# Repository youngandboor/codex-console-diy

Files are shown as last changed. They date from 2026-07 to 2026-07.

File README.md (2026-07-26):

# Codex Console DIY

Personal-use ESP32-S3 control surface compatible with Codex Micro features in
ChatGPT Desktop. The target is functional equivalence rather than a mechanical
copy: similar control grouping and lighting, Bluetooth LE, native USB, and a
single-cell rechargeable battery.

This repository is an independent compatibility experiment. It is not
affiliated with or endorsed by OpenAI or Work Louder. The compatibility
identity and undocumented protocol are used only for personal interoperability
testing.

## Current milestone

Phase 0 provides:

- the exact 63-byte vendor HID framing used by the Core2 reference project;
- a bounded, allocation-free receive assembler;
- BLE and native USB HID transports on ESP32-S3;
- USB-first transport routing, with BLE fallback;
- the observed Codex RPC methods and six Agent status values;
- two breadboard inputs on GPIO4/GPIO5 using external Agent 1/Agent 2 buttons;
- native unit tests for framing, fragmentation, validation, and recovery.

Physical key scanning, RGB output, the joystick, encoder, fuel gauge, and sleep
policy are intentionally the next milestone. The USB protocol is implemented
as an informed compatibility hypothesis and still requires validation against
ChatGPT Desktop before a PCB is ordered.

## Build

```sh
pio test -e native
pio run -e esp32-s3-devkitc-1
```

For the development-board smoke test, use an ESP32-S3 DevKitC-1 native USB
port. Connect normally-open buttons from GPIO4 and GPIO5 to a shared GND;
pressing them sends Agent 1 and Agent 2 events respectively. The firmware
enables the GPIO internal pull-ups, so no external resistors are required. The
earlier GPIO0/BOOT bench input was only used for first-board validation and is
no longer used as a user control.

## Project boundaries

- `src/protocol`: transport-independent HID framing and Codex RPC behavior.
- `src/transports`: BLE HOGP and ESP32-S3 native USB HID.
- `src/main.cpp`: Phase 0 orchestration only.
- `docs/hardware-v1.md`: interaction layout, electrical architecture, and PCB
  gates.
- `docs/development-plan.zh-CN.md`: parallel firmware, product, and PCB plan.
- `docs/purchase-checklist.zh-CN.md`: staged beginner purchase checklist and
  order gates.
- `docs/wireless-audio-options.zh-CN.md`: 2.4 GHz dongle and BLE Audio tradeoff
  analysis.
- `docs/hardware-validation-log.zh-CN.md`: dated physical-hardware validation
  results.
- `docs/validation.md`: tests required before moving from breadboard to PCB.
- `hardware/rev-a`: integrated Alpha PCB, enclosure, placement, BOM, and 1:1
  mechanical design baseline.

The original Core2 project remains a read-only behavioral reference in the
sibling `codex-micro-4-core2` directory.

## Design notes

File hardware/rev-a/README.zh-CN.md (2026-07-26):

# Codex Console Alpha Rev A

本目录是第一版集成样品的设计基线。目标不是一次量产成功，而是用一套可装配的
PCB、外壳和真实控件同时验证功能、手感、灯光、电源和装配。

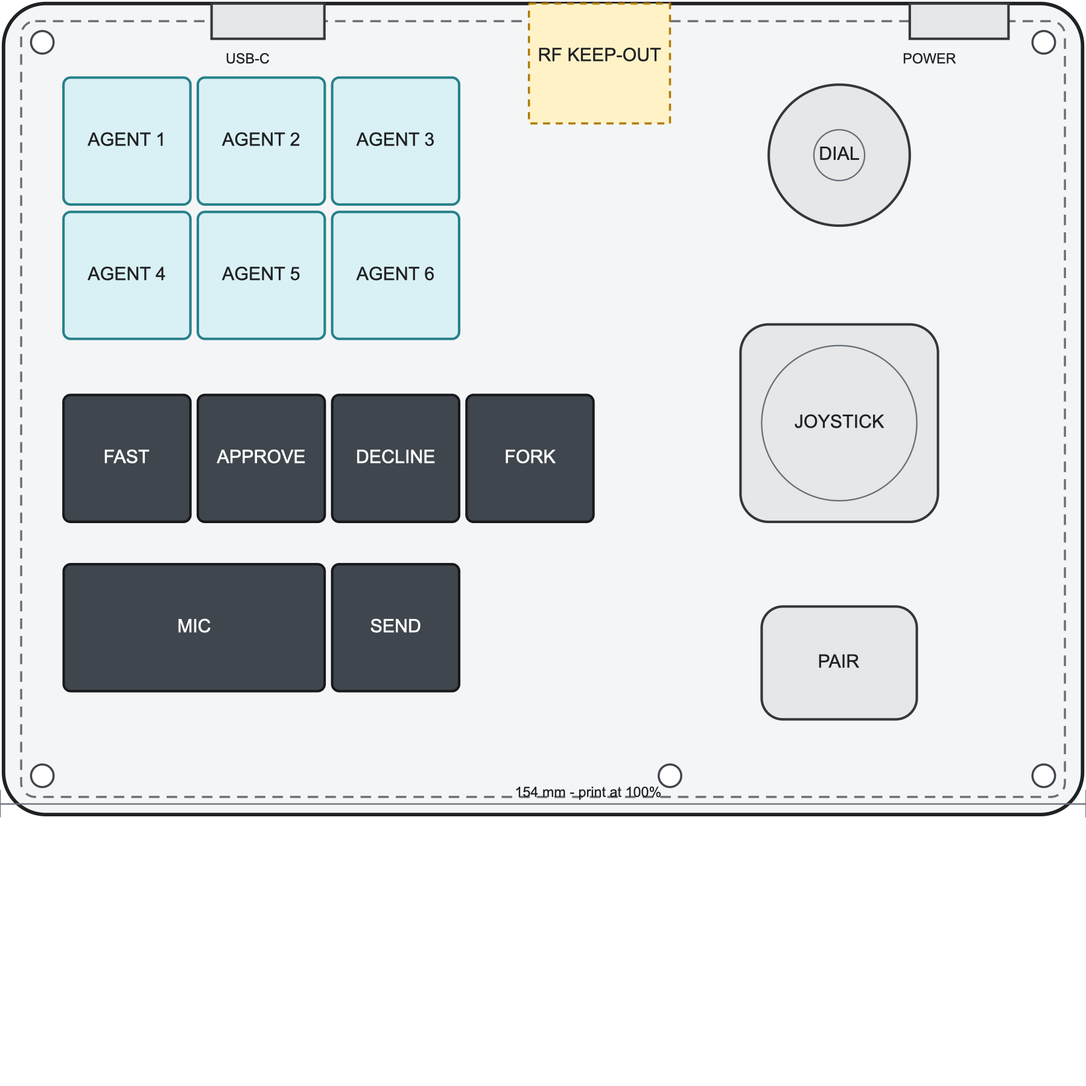
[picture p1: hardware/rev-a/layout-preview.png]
Rev A 顶视布局


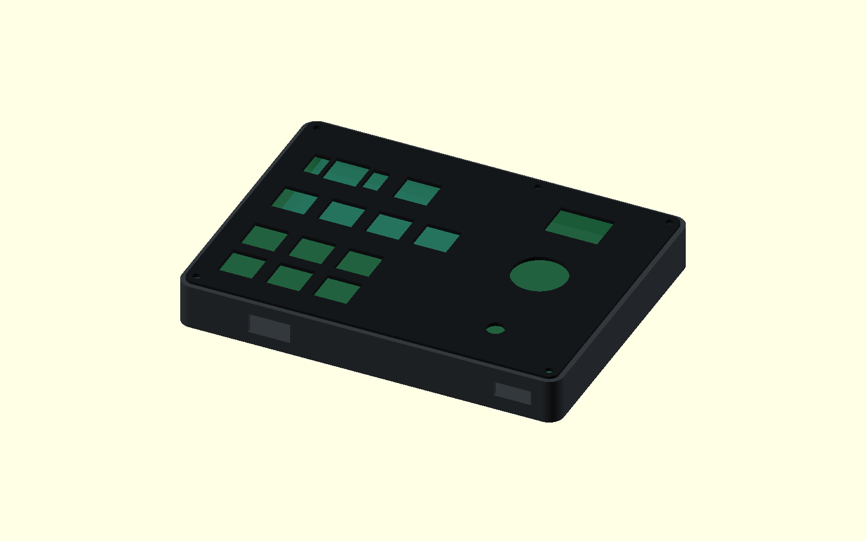
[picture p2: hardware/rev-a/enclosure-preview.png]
Rev A 外壳参数模型


## 已冻结的产品方向

| 项目 | Rev A 决策 |
| --- | --- |
| 外壳外形 | 154 x 116 mm，圆角桌面控制台 |
| 主 PCB | 148 x 110 mm，4 层，1.6 mm，优先 SMT 贴片 |
| 按键 | 12 个 MX 热插拔轴，PCB 同时兼容 3 脚和 5 脚，19.05 mm 间距 |
| 键帽 | XDA 等高；6 个磨砂半透明 1U Agent，5 个深灰 1U Command，1 个深灰 2U Mic |
| 轴体 | Alpha 默认 Gateron G Pro 3.0 Brown，透明上盖、5 脚；热插拔允许后续替换 |
| Mic 稳定器 | PCB 安装 2U 螺丝卫星轴 |
| 旋钮 | Alps Alpine EC11E15244G1，30 段、15 脉冲、带按压、20 mm D 轴 |
| 摇杆 | Alps Alpine RKJXV122400R，回中双轴、10 kOhm、带中心按压 |
| 主控 | ESP32-S3-WROOM-1-N8R8 |
| 连接 | BLE HID + 原生 USB 2.0 Full Speed，USB 有线优先 |
| 灯光 | 12 个按键灯 + 8 个边缘灯，共 20 个 SK6812MINI-E |
| 电池 | 预留受保护 1S 604070 LiPo，最大包络 70 x 40 x 7 mm，JST-PH 2.0 |
| 充电 | BQ24074 PowerPath，允许插线使用和充电 |
| 板载麦克风 | 预留 PDM 器件和声孔，Rev A 默认 DNP，不启用 USB Audio |

Mic 键在 Rev A 中继续调用电脑麦克风。这保持与已经验证的 Codex Micro HID 行为
一致。板载麦克风只有在 USB Audio 复合设备和无线语音方案分别验证后才装配。
Rev A 不集成专用 2.4 GHz 接收器，也不承诺 BLE Audio；两者继续作为后续独立版本，
不阻塞当前 BLE HID + USB 样品。

## 电气构成

```mermaid
flowchart LR
    USB["USB-C VBUS"] --> ESD["USB/ESD 保护"]
    ESD --> CHG["BQ24074 PowerPath"]
    BAT["1S 受保护 LiPo"] --> CHG
    BAT --> GAUGE["MAX17048 电量计"]
    CHG --> SYS["系统电源轨"]
    SYS --> REG3["TPS63070 3.3 V"]
    SYS --> REG5["TPS61023 5 V RGB"]
    REG3 --> MCU["ESP32-S3-WROOM-1-N8R8"]
    REG5 --> LED["20 x SK6812MINI-E"]
    MCU --> MATRIX["4 x 4 按键矩阵"]
    MCU --> ENC["EC11 旋钮"]
    MCU --> JOY["双轴摇杆"]
    MCU --> USBHID["原生 USB HID"]
    MCU --> BLE["BLE HID"]
```

## 坐标和堆叠

- 所有平面坐标以外壳左上角为 `(0, 0)`，单位为 mm。
- PCB 位于外壳内侧，每边留 3 mm。
- PCB 下方预留 9 mm 电池层，并使用绝缘电池托盘隔开热插拔轴座和电芯。
- MX 定位板到 PCB 的名义距离为 5.0 mm，定位板厚 1.5 mm。
- 外壳主体高度 18 mm；键帽和旋钮露出主体，不计入 18 mm。
- 后边缘布置 USB-C、电源开关和模块天线区域；天线前方及上下层不得放置金属。

## 文件

- `layout.svg`：154 x 116 mm 的 1:1 顶视布局，可按 100% 比例打印。
- `enclosure.scad`：参数化底壳、定位板、孔位和占位体。
- `placement.csv`：控件中心和机械包络，PCB 与外壳共用。
- `mechanical-placement.kicad_pcb`：四层 PCB 板框、安装孔、控件包络和天线/电池区的
  KiCad 机械基线；它不是已布线生产板。
- `mechanical-placement-preview.png`：KiCad 机械基线的独立导出预览。
- `lceda/Codex Console Rev A.eprj2`：嘉立创 EDA 专业版 V3.2.166 的正式本地工程；
  原理图和 PCB 将以此为后续主设计文件。
- `net-map.csv`：GPIO、矩阵和主要网络分配。
- `pcb-rules.md`：四层板、电源、USB、天线和可制造性约束。
- `bom.csv`：Rev A 关键电气与机械 BOM；小阻容在原理图完成时补齐数值。
- `sources.md`：关键芯片与控件的原厂资料入口。
- `procurement.zh-CN.md`：机械样品、PCBA 物料和电池的分批下单边界。
- `release-checklist.zh-CN.md`：PCB 下单和外壳打印前必须关闭的 P0 检查项。

## 当前完成度

机械基线已使用 KiCad 10.0.5 执行 DRC，结果为 0 条违规、0 个未连接项；参数外壳已
使用 OpenSCAD 2021.01 完成编译渲染。这里的 DRC 只证明板框、安装孔和机械图层合法，
不代表尚未绘制的电路已经通过验证。

同一机械基线已导入嘉立创 EDA 专业版工程，文档名为 `mechanical-placement`。空白的
`PCB1` 和 `Schematic1` 是软件创建工程时生成的占位文档，不代表导入失败。

这是可用于原理图捕获和结构样件的 Rev A 基线，还不是可以直接发板的生产包。发板前
必须完成：正式 KiCad 原理图、封装核对、ERC、PCB 布线、DRC、Gerber/钻孔复查、
3D 干涉检查和电池极性复核。第一次只投 5 片 PCB 和 2 套打印外壳。

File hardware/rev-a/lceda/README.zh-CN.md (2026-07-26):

# 嘉立创 EDA 专业版工程

- 软件版本：嘉立创 EDA 专业版 `V3.2.166`
- 工程文件：`Codex Console Rev A.eprj2`
- 保存模式：本地半离线工程
- 当前内容：`Board1 / Schematic1 / P1 / PCB1 / mechanical-placement`

`mechanical-placement` 已从 `mechanical-placement-kicad.zip` 导入，并在 PCB 编辑器中
确认可见：包含 148 x 110 mm 板框、5 个 M3 安装孔、12 键包络、旋钮、摇杆、触控区、
电池区和天线区。原始的 `PCB1` 仍是空白占位页。

`Schematic1 / P1` 仍为空白，因为此前完成的是产品布局和 PCB 机械基线，并不是正式
电路原理图。后续将在这里完成 ESP32-S3、USB、电源、矩阵、旋钮、摇杆、RGB 的电路、
封装、布线、ERC、DRC 和生产文件导出。

不要直接用 SQLite 工具修改 `.eprj2`。所有设计变更必须通过嘉立创 EDA 专业版完成，
关闭或保存工程后再提交 Git。

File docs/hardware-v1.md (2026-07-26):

# Hardware v1 specification

## Interaction layout

The control surface keeps the original functional grouping without copying its
case or industrial design:

- six translucent Agent keys in a 3 x 2 block, each with independent RGB;
- six Command keys grouped below the Agent keys;
- a 2U Mic key and five 1U Command keys are preferred for a familiar layout;
- a push rotary encoder in the upper-right control area;
- a two-axis analog joystick beside or below the encoder;
- one separate capacitive or tactile communication control near the lower-left;
- perimeter RGB for recording, processing, connection, and charging effects.

Suggested logical arrangement:

```text
AGENT 1   AGENT 2   AGENT 3                 DIAL
AGENT 4   AGENT 5   AGENT 6               JOYSTICK
FAST      APPROVE   DECLINE    FORK
MIC (2U)             SEND      COMM/PAIR
```

The functional input count is 12 keys plus encoder push. The matrix should be
4 x 4 with one diode per switch, leaving spare positions for a local layer or
diagnostic key. The encoder quadrature lines and joystick axes remain direct
MCU inputs.

## Lighting

Use one addressable chain with explicit logical ranges:

| Range | Count | Purpose |
| --- | ---: | --- |
| Agent RGB | 6 | Host-provided task color and breathing state |
| Command RGB | 6 | Command feedback and local press feedback |
| Perimeter RGB | 8 | Moving voice, processing, pairing, and charge effects |

The firmware must cap global brightness and estimated LED current. Agent state
colors take priority over decorative effects. USB and battery operation use the
same visual policy; plugging in USB must not force all LEDs to full brightness.

## Core electronics

- MCU/module: ESP32-S3-WROOM-1, 8 MB flash is sufficient; PSRAM is optional.
- USB: native ESP32-S3 USB D-/D+ on GPIO19/GPIO20, USB-C device connector,
  5.1 kohm CC pull-downs, ESD protection, and 22/33 ohm series footprints.
- Power: 1-cell protected LiPo, nominal 1,500-2,000 mAh.
- Charger: BQ24074-class charger with power-path/load sharing. Do not connect a
  basic charger module, battery, USB rail, and system load in parallel.
- 3.3 V: regulator rated for at least 500 mA with the decoupling recommended by
  Espressif.
- Fuel gauge: MAX17048 or equivalent 1-cell gauge over I2C.
- RGB logic: dual-supply level shifter between 3.3 V MCU data and the LED rail.
- Controls: MX-compatible hot-swap footprints for ease of DIY assembly, EC11
  push encoder, and a spring-centered two-axis analog joystick.
- Service: physical power switch, reset, boot pads/button, UART pads, battery
  connector, and current-measurement jumper.

## Proposed GPIO allocation

This allocation avoids USB pins, boot strapping pins, and pins that may be
occupied by octal flash/PSRAM variants:

| Function | GPIO |
| --- | --- |
| Matrix rows | 4, 5, 6, 7 |
| Matrix columns | 8, 9, 10, 11 |
| Encoder A/B | 12, 13 |
| Joystick X/Y (ADC) | 1, 2 |
| Communication touch control | 14 |
| Addressable RGB data | 15 |
| Fuel gauge I2C SDA/SCL | 17, 18 |
| USB D-/D+ | 19, 20 |
| Charger status | 16, 21 |
| UART service pads | 43, 44 |

Encoder push occupies one position in the 4 x 4 matrix. Reserve the other
unused matrix positions rather than assigning them to mandatory v1 features.
Place a 510 ohm series footprint at the MCU end of the touch trace.

## Transport policy

Both transports may remain initialized, but only one sends user actions:

1. A mounted and ready USB HID connection has priority.
2. If USB is only supplying power or charging but is not enumerated, BLE stays
   active.
3. After USB unmounts, release all active logical controls before switching to
   BLE so no key remains logically held.
4. RPC responses return over the transport that received the request.
5. Lighting commands from the active transport win; inactive-host lighting is
   ignored after the protocol validation milestone.

## PCB gates

Do not order the integrated battery PCB until all of these pass on a DevKitC-1:

- ChatGPT Desktop recognizes both BLE and USB identities;
- Agent and Command actions work over both transports;
- USB priority does not duplicate a press on BLE;
- disconnect during a held key produces a clean release after reconnection;
- six Agent status colors are received and replayed reliably;
- native USB is revalidated after every descriptor or SDK change.

For Alpha Rev A, the user has explicitly accepted an integrated-board fast track after USB, BLE,
two-button input, and USB/BLE priority were validated. Matrix, RGB, encoder, joystick, and battery
validation may therefore happen on the first five integrated boards. This exception does not waive
ERC, DRC, footprint, USB-impedance, antenna-keepout, battery-polarity, or staged-power-up reviews.

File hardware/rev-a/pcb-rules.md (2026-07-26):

# PCB Rev A rules

## Stackup and fabrication

- Four layers, 1.6 mm finished thickness, 1 oz outer copper.
- L1: components and short critical signals.
- L2: uninterrupted ground plane except the certified module antenna keepout.
- L3: power distribution and slow signals.
- L4: hot-swap sockets, reverse RGB, diodes and non-critical routing.
- Default minimum track/space 0.15/0.15 mm; use 0.20 mm where density permits.
- Signal vias 0.45/0.20 mm finished; do not use via-in-pad for the Alpha.
- All QFN exposed pads require paste-window reduction and ground thermal vias based on the
  manufacturer's current land pattern.

## USB

- Route GPIO19/GPIO20 as a 90 Ohm differential pair using the PCB supplier's actual stackup.
- Keep pair length mismatch below 0.5 mm and avoid vias. Do not guess the final width/gap before
  selecting the fabricator impedance table.
- Place the 22 Ohm series footprints at the ESP32 module, and the ESD array at the connector.
- Provide 5.1 kOhm Rd resistors on both USB-C CC pins. Do not connect USB-C SuperSpeed pins.
- Set the BQ24074 input-current limit conservatively for a USB host and verify suspend/configured
  behavior during schematic review; do not assume every USB-C source permits 1.5 A or 3 A.
- Keep switching inductors and the RGB data edge away from the USB pair.

## RF

- Put the ESP32-S3-WROOM-1 antenna at the rear board edge.
- Copy the current Espressif module land pattern and antenna keepout from the official datasheet.
- No copper, traces, battery, screws, metal plate or shield above or below the antenna keepout.
- Use a plastic rear wall near the antenna; the switch plate must stop before the keepout.

## Power

- VBUS feeds BQ24074 IN through protection; BQ24074 OUT feeds the 3.3 V and 5 V converters.
- The physical power switch controls converter EN pins. Charging and fuel measurement remain
  available while the user-facing electronics are off.
- Use a dedicated 3.3 V buck-boost for ESP32 and analog controls. Do not power ESP32 directly from
  the LiPo or the charger's dynamic system rail.
- The 5 V RGB rail must default off at reset. GPIO42 enables it only after firmware sets a current
  ceiling.
- Size the RGB rail for 1.5 A, but cap firmware brightness so normal operation remains below 700 mA.
- Use wide pours for BAT/SYS/5V_LED, short switching loops, and the exact regulator reference
  layouts. Keep both switch nodes away from joystick ADC and the antenna.
- Put a removable 0 Ohm current-measurement link between the battery connector and system.

## Inputs and lighting

- Use 1N4148W diodes on all populated matrix controls, with one common orientation documented on
  silkscreen.
- Put test pads on all four rows, all four columns, encoder A/B, joystick X/Y, RGB data, 3V3,
  5V_LED, SYS, BAT and GND.
- Reverse-mount SK6812MINI-E pixels require verified cutouts and orientation marks on both sides.
- Maintain a continuous ground reference beneath joystick ADC traces; add optional 1 kOhm/100 nF
  low-pass footprints at the MCU end.

## Mechanical and service

- Board outline is 148 x 110 mm inside a 154 x 116 mm enclosure.
- Use five M3 supports. No unsupported span may exceed 80 mm near frequently pressed keys.
- Keep the 70 x 40 x 7 mm battery envelope in a separate lower tray with a rigid insulating sheet.
- Expose BOOT and RESET through recessed pinholes; expose UART TX/RX/GND/3V3 as labeled pads.
- Add clear pin-1, diode direction, LED direction, battery polarity and connector labels.

## Release checks

Rev A may be ordered only after ERC and DRC are clean, every custom footprint is checked against a
manufacturer drawing at 1:1 scale, the USB pair is recalculated for the chosen stackup, and the
complete assembly passes a 3D interference review. Order five boards, assemble one without a
battery first, and current-limit the first power-up.

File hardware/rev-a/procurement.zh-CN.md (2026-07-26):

# Alpha Rev A 采购与打样顺序

快速推进不等于一次把所有物料散买回来。机械样品需要立刻到手，QFN 电源芯片则由
PCB 贴片厂随板装配，避免个人手焊造成不可诊断的问题。

## 现在购买：机械与手感冻结

| 物料 | 数量 | 下单关键词或型号 | 用途 |
| --- | ---: | --- | --- |
| MX 轴体 | 20 | Gateron G Pro 3.0 Brown，5 脚，透明上盖 | 12 个装机，8 个备件 |
| MX 热插拔轴座 | 20 | Kailh MX hot-swap socket 正向 | 封装和装配样品 |
| Agent 键帽 | 6 | XDA，1U，磨砂半透明 PC，MX 十字 | 状态灯扩散 |
| Command 键帽 | 5 | XDA，1U，深灰 PBT 空白 | 后续 UV 打印图标 |
| Mic 键帽 | 1 | XDA，2U，深灰 PBT 空白 | 2U 结构样品 |
| 2U 卫星轴 | 2 套 | PCB 安装、螺丝固定、2U | 一套装机一套备件 |
| 编码器 | 2 | Alps Alpine EC11E15244G1 | 一件测量、一件装机 |
| 旋钮 | 各 1 | 20 mm 直径、D 轴；铝和塑料各一个 | 比较手感和无线影响 |
| 摇杆 | 先询价 | Alps Alpine RKJXV122400R | 只从授权渠道购买；接受最小包装前先看总价 |
| 紧固件 | 1 套 | M3 热熔螺母、M3x6/M3x10 螺丝 | PCB 和外壳固定 |
| 电池体积块 | 1 | 70 x 40 x 7 mm 泡棉或 3D 打印块 | 先检查空间，不买真电池 |

轴体采用热插拔，所以 Brown 只是 Alpha 的默认触感，不会锁死最终选择。PCB 封装兼容
3 脚和 5 脚 MX 轴；Gateron 官方为 G Pro 3.0 Brown 提供两种版本，本轮明确购买
5 脚版本，并仍然使用定位板。
键帽必须统一 XDA 等高轮廓，不能混入 OEM 不同行高。购买半透明 Agent 键帽时优先要
实物透光照片，避免“透明”实际只是侧面透光。

`RKJXV122400R` 是当前型号，但授权渠道可能按整盘销售。先询问能否提供 1-2 件工程
样品；若只能按 25 件起订，先确认总价再决定，不要用已标记为不推荐新设计的
`RKJXV1224005` 悄悄替代。

## 随 PCB 贴片：不要个人散焊

以下器件应在正式 BOM 和坐标文件完成后由贴片厂采购或代贴：

- ESP32-S3-WROOM-1-N8R8；
- BQ24074、TPS63070、TPS61023、MAX17048；
- USB ESD、AHCT 缓冲器、SK6812MINI-E、贴片二极管和小阻容；
- USB-C、JST-PH、滑动电源开关。

不要为了“先买到”而替换封装或近似型号。任何替代都必须先更新原理图、封装和 BOM。

## 结构确认后购买

- 受保护 1S LiPo，1500-2000 mAh，最大 70 x 40 x 7 mm；
- JST-PH 2.0，必须按照 PCB 丝印和万用表结果复核极性；
- 最终外壳材料和表面处理；
- 自定义图标键帽或 UV 打印服务。

板载 PDM 麦克风、2.4 GHz 接收器和 BLE Audio 器件本轮不采购。

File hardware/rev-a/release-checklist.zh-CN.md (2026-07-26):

# Rev A 发板与打印检查表

这份清单把“设计完成”和“可以花钱生产”分开。所有 `P0` 项通过后才允许下单
PCB；结构件可以先打印低成本草样，但不得据此购买真电池。

## P0：PCB 下单前必须关闭

- [ ] KiCad 原理图完成，所有器件型号、阻容值和电源时序已填写。
- [ ] ERC 无未解释错误；保留的警告逐条写明原因。
- [ ] 所有封装按原厂尺寸图和一件实物二次核对，尤其是 USB-C、EC11、摇杆、
  热插拔轴座、2U 卫星轴和滑动开关。
- [ ] USB D+/D- 按板厂真实四层叠层计算 90 Ohm 差分阻抗，不使用猜测线宽。
- [ ] ESP32-S3 天线净空满足原厂数据手册；净空区上下层无铜、无电池、无螺钉。
- [ ] BQ24074 充电电流根据最终电芯规格设定，热焊盘和散热铜满足原厂建议。
- [ ] 3.3 V 与 5 V 电源分别完成最坏负载、启动、关断和反灌电流检查。
- [ ] DRC 无未解释错误；Gerber、钻孔、板框和阻焊文件用独立查看器复核。
- [ ] 先生产 5 片，其中只贴 2 片；第一片不装电池，限流电源分电源域上电。

## P0：外壳打印前必须关闭

- [ ] 以 100% 比例打印 `layout.svg`，实物摆放确认手距、2U Mic 和摇杆行程。
- [ ] 核对 G Pro 3.0 Brown、EC11、摇杆、卫星轴、USB-C 和开关的实际高度。
- [ ] 外壳螺柱与 PCB 焊盘、轴座、电池、天线净空无干涉。
- [ ] 2U 定位板开口和卫星轴开口使用所购实物尺寸，而不是通用估计值。
- [ ] USB 插头完全插入时不顶壳；电源开关可操作且不会被误触。
- [ ] 电池托盘无锐角，电芯与焊点之间有刚性绝缘片，且可无损拆卸。
- [ ] 先打印 2 套：一套便宜材料装配验证，一套在修正后验证灯光扩散。

## 仍可在 Alpha 后修改

- 轴体触感与键帽图标；
- 外壳表面处理、颜色和边缘灯扩散材料；
- 板载 PDM 麦克风是否装配；
- 后续独立 2.4 GHz 接收器版本。

这些项目不应阻塞 Rev A，但任何影响 PCB 封装、开孔或射频净空的修改都必须重新跑
ERC、DRC 和 3D 干涉检查。

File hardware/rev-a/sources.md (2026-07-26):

# Rev A primary references

Use the latest English manufacturer datasheet, package drawing, reference schematic, and layout
guidance at schematic-capture time. Distributor previews are not a substitute for these sources.

- [ESP32-S3-WROOM-1 / WROOM-1U datasheet v1.8](https://documentation.espressif.com/esp32-s3-wroom-1_wroom-1u_datasheet_en.pdf)
- [TI BQ24074 product page and BQ2407x datasheet](https://www.ti.com/product/BQ24074)
- [TI TPS63070 buck-boost product page](https://www.ti.com/product/TPS63070)
- [TI TPS61023 5 V boost product page](https://www.ti.com/product/TPS61023)
- [Analog Devices MAX17048 fuel-gauge product page](https://www.analog.com/en/products/max17048.html)
- [TI SN74AHCT1G125 level-buffer product page](https://www.ti.com/product/SN74AHCT1G125)
- [TI TPD2EUSB30 USB ESD product page](https://www.ti.com/product/TPD2EUSB30)
- [Alps Alpine EC11E encoder catalog](https://tech.alpsalpine.com/assets/catalog/product-catalog-ec-01.en.pdf)
- [Alps Alpine RKJXV122400R current joystick series](https://tech.alpsalpine.com/e/products/category/muiti-control-devices/sub/01/series/rkjxv/)
- [Gateron G Pro 3.0 switch series](https://www.gateron.com/products/gateron-g-pro-30-switch-set)
- [ESP32-S3 touch sensor and GPIO mapping](https://docs.espressif.com/projects/esp-idf/en/v5.4/esp32s3/api-reference/peripherals/touch_pad.html)
- [ST MP34DT06J optional PDM microphone datasheet](https://www.st.com/resource/en/datasheet/mp34dt06j.pdf)

The joystick baseline intentionally uses `RKJXV122400R`, which Alps Alpine lists as a current
standard part. The older and more commonly referenced `RKJXV1224005` is marked not recommended for
new designs and must not be used as the Rev A purchasing part number.

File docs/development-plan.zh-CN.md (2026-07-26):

# Codex Console DIY 并行开发计划

更新日期：2026-07-26

## 核心原则

项目按“功能兼容最终能够验证成功”推进产品设计，不等待协议工作全部结束才开始键盘
设计。可逆的设计和样机工作并行进行；只有 PCB 投产、电池定型和最终外壳加工等
不可逆、成本较高的动作需要等待对应验证门槛。

## 2026-07-26 Alpha 快速推进决策

USB、BLE、外接多按键和双传输自动切换已经实机通过。项目不再等待矩阵、RGB、
旋钮、摇杆和电池分别完成面包板验证，而是直接设计一块集成 PCB Alpha 和配套
3D 打印外壳，用同一套样品完成剩余验证。该决策接受一次 PCB 改版的成本，但不降低
电池、USB 和首次上电的安全检查。

- Rev A 同时包含完整输入、20 颗 RGB、PowerPath、燃料计和电池机械包络。
- 第一次只做 5 片 PCB、2 套外壳；先无电池限流上电，再接电源模块，最后接受保护电池。
- 板载麦克风只预留且默认不贴，避免 USB Audio/BLE Audio 风险进入主样品关键路径。
- 发板门槛改为原理图/ERC/DRC/封装/3D/极性审查完成，不再要求全部子系统先过面包板。

## 三条并行主线

| 主线 | 当前工作 | 阶段输出 |
| --- | --- | --- |
| 功能与固件 | BLE/USB HID、按键矩阵、旋钮、摇杆、RGB、电池策略 | 可重复测试的固件和验证记录 |
| 产品与结构 | 1:1 布局、操作间距、键帽和手感、灯光扩散、外壳与装配 | 尺寸图、外壳样件和交互决策 |
| 电路与 PCB | 原理图、功耗预算、器件选型、封装、布局布线和可制造性 | 原理图 Rev A、PCB Rev A 和生产 BOM |

三条主线共享同一份接口基线：ESP32-S3-N8R8、12 个命令/Agent 键、编码器按压、
双轴摇杆、20 颗可寻址 RGB、BLE 和原生 USB、单节锂电池。

## 同步里程碑

| 里程碑 | 功能与固件 | 产品与结构 | 电路与 PCB |
| --- | --- | --- | --- |
| M0 架构冻结 | 双传输和 RPC 框架 | 控件数量及分组 | GPIO 和电源框图 |
| M1 单控件验证 | USB/BLE 单按键 | 1:1 纸面/打印布局 | 原理图框架和器件库 |
| M2 完整台架 | 矩阵、旋钮、摇杆、20 RGB | 控件手感、间距、扩散样件 | 原理图 Rev A、PCB 外形草案 |
| M3 电源样机 | 充电、续航、切换和休眠 | 外壳 Rev A、内部堆叠 | PCB Layout Rev A、生产 BOM |
| M4 集成 Alpha | 全功能回归 | 完整装配样机 | 首批 5 片 PCB 投产 |
| M5 Beta | 稳定性和异常恢复 | 人体工学与灯效微调 | PCB/外壳修订 |

## 下单门槛

- 1:1 布局、纸模、3D 外壳草模和原理图可以立即开始。
- 通用样品件可以在第二批购买，用于比较手感、高度和灯光扩散。
- PCB 可以提前完成到 Rev A，但 USB 与 BLE 均未通过时不投产。
- 电池可以先完成容量和堆叠设计，实际型号在内部空间和峰值功耗确定后下单。
- 最终 EC11 轴高、摇杆高度、键帽和卫星轴由结构样机决定。
- 集成 Alpha 可在协议和双传输通过后投产，但必须完成正式电气与机械设计审查；
  输入、灯光和电源的剩余风险由首批 5 片 Alpha 承担。

## 第二批中的设计样品

第二批不再只有面包板功能件，同时采购以下低风险设计样品：

| 样品 | 建议数量 | 要验证的问题 |
| --- | ---: | --- |
| MX 透明轴试轴包 | 线性/段落/有声各 3 个 | 最终手感和噪声 |
| MX 透光空白键帽 | 1U 十二个、2U 一个 | 间距、透光、标签方案 |
| 2U 卫星轴 | 板装和 PCB 装各 1 套 | Mic 键结构和装配难度 |
| 凯华 MX 热插拔轴座 | 20 个 | PCB 封装和可维护性 |
| EC11 编码器 | 15 mm、20 mm 轴高各 1 个 | 旋钮露出高度和手感 |
| 编码器旋钮 | 直径约 15/18/20 mm 各 1 个 | 手指空间和外观比例 |
| 摇杆样品 | PS2 全尺寸、PSP 紧凑型各 1 个 | 行程、精度、安装高度 |
| 半透明材料小样 | 乳白亚克力或半透明 PETG，1-3 mm | RGB 扩散和亮点控制 |
| 数显卡尺 | 0-150 mm | 实物封装和外壳尺寸测量 |

第二批样品的任务是做选择，不要求所有样品进入最终产品。选择结果要记录到硬件
规格和 PCB BOM，避免后续仅凭商品名称替换尺寸不兼容的零件。

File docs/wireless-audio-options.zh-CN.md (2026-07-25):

# 无线麦克风方案评估

更新日期：2026-07-25

## 评估前提

- 设备主要服务于 ChatGPT Desktop，macOS 优先，Windows 其次。
- 麦克风用于按住说话和短时间连续录音，不承担音乐播放或全双工耳机功能。
- 电脑侧应免安装常驻配套程序。
- 保留 Codex Micro 兼容 HID、BLE、原生 USB 和单节锂电池。
- 当前主控和验证平台为 ESP32-S3。

## 结论

如果必须让键盘在无线状态下使用自身麦克风，主线选择专用 2.4 GHz USB 接收器。
BLE Audio 作为研究支线保留，不作为第一版成品依赖。

推荐发布顺序：

1. v1：USB 有线时使用键盘麦克风；BLE 时使用电脑麦克风。
2. v1.5：增加可选 2.4 GHz USB 接收器，传输 HID 和麦克风音频。
3. Research：用 nRF5340 Audio DK 验证目标电脑的原生 BLE Audio 麦克风兼容性。

## 方案 A：专用 2.4 GHz USB 接收器

### 架构

```mermaid
flowchart LR
    Mic["键盘 PDM/I2S 麦克风"] --> Capture["采样和语音编码"]
    Keys["按键、旋钮、灯光 RPC"] --> RadioTX["2.4 GHz 控制与音频协议"]
    Capture --> RadioTX
    RadioTX --> RadioRX["USB 接收器"]
    RadioRX --> Audio["USB Audio Class 麦克风"]
    RadioRX --> HID["USB Vendor HID"]
    Audio --> Host["macOS / Windows"]
    HID <--> Host
```

键盘和接收器都可以使用 ESP32-S3。接收器向电脑呈现为复合 USB 设备：一个标准
UAC 麦克风接口加一个 Codex 兼容 Vendor HID 接口。电脑不需要知道无线协议。

### 建议传输策略

- 语音基线为单声道、16 kHz、16 bit；原始数据率约 256 kbit/s。
- 先用 IMA-ADPCM 一类低复杂度语音编码降低无线占用，接收器恢复为 PCM。
- 音频采用序号、时间戳和短抖动缓冲；过期音频包不重传，可选轻量冗余或丢包隐藏。
- HID/RPC 使用独立高优先级可靠队列，必须确认并重传，不能被音频流阻塞。
- 配对后保存唯一密钥，加入加密、随机数和重放保护。
- 插入接收器时优先使用 2.4 GHz；BLE 停止发送控制事件，避免重复输入和射频争用。
- 接收器将主机下发的 Agent 灯光状态反向转发给键盘。

ESP-NOW 可用于第一版无线台架。它默认 1 Mbit/s，v2.0 单包最多 1470 字节并支持
CCMP，但官方明确说明 MAC 层发送成功不等于应用层收到，而且过短发送间隔可能造成
回调次序问题。因此必须自行实现序号、确认、缓冲和丢包策略。正式版还要对比
ESP-NOW、Wi-Fi UDP 和专用 2.4 GHz 收发方案后再冻结。

### 优点

- 继续使用现有 ESP32-S3、固件和开发工具。
- USB UAC/HID 对电脑端最可控，绕开电脑蓝牙芯片和驱动差异。
- 同一个无线链路可以传音频、按键和灯光双向数据。
- 可以针对语音优化延迟、带宽和电池消耗。
- 接收器可以承担恢复烧录、日志和固件升级入口。

### 风险和代价

- 需要第二块 PCB、USB 外壳和另一套固件。
- 占用一个 USB 口，接收器可能丢失。
- 需要自行处理配对、抗干扰、抖动、丢包、加密和版本兼容。
- ESP32-S3 的 Wi-Fi 类 2.4 GHz 传输功耗高于普通 BLE HID；应只在录音期间开启高吞吐。
- 音频流和灯光/RPC 的压力测试工作量明显增加。

## 方案 B：原生 BLE Audio

### 架构

```mermaid
flowchart LR
    Mic["PDM 麦克风"] --> LC3["LC3 编码"]
    LC3 --> LEAudio["BLE Audio 等时通道"]
    HID["Codex HID"] --> BLE["Bluetooth LE"]
    LEAudio --> Host["电脑原生蓝牙音频"]
    BLE <--> Host
```

真正的 BLE Audio 依赖 Bluetooth Core 5.2 引入的 LE Isochronous Channels，并使用
LC3 和相关音频 Profile。ESP32-S3 是 Bluetooth 5.0 LE 平台，不具备这条完整路线，
因此不能只靠固件升级实现。

可行的验证平台是 Nordic nRF5340。它支持 LE Audio、PDM/I2S、USB 2.0 Full Speed，
Nordic 的 Audio DK 可作为 USB dongle、音频终端或耳机参考平台。

### 两种实现方式

| 方式 | 结果 | 问题 |
| --- | --- | --- |
| nRF5340 直接连接电脑 BLE Audio | 无接收器 | 强依赖电脑蓝牙硬件、系统和驱动支持 |
| 两块 nRF5340 Audio DK，其中一块作 USB 网关 | 兼容性更可控 | 最终仍然是“带接收器”的方案，成本和复杂度更高 |

### 优点

- 标准化音频链路，LC3 为低码率和低功耗设计。
- 理想条件下无需专用接收器。
- 音频时序、QoS 和等时传输由标准协议栈处理。
- 适合后续扩展成完整无线音频产品。

### 风险和代价

- 需要把主控迁移到 nRF5340，或增加第二颗无线 SoC。
- Codex HID、USB、RGB、矩阵、电池和升级代码都要移植到 Nordic/Zephyr 生态。
- LE Audio 的 Profile、LC3、等时通道和配对调试门槛远高于普通 BLE HID。
- Windows 官方明确说明并非所有 Windows 11 电脑都支持 LE Audio，还依赖出厂硬件和
  厂商驱动。目标 macOS 的第三方 BLE Audio 麦克风也必须实机验证，不能由规格推断。
- 若为了兼容性再配一只 Nordic USB 网关，会失去“无接收器”的主要优势。

## 对比

| 维度 | 专用 2.4 GHz 接收器 | 原生 BLE Audio |
| --- | --- | --- |
| 复用 ESP32-S3 | 高 | 低 |
| macOS/Windows 免驱确定性 | 高，电脑只看到 USB UAC/HID | 中低，取决于蓝牙硬件、系统和驱动 |
| 无需接收器 | 否 | 理论上是 |
| 固件开发难度 | 中高 | 很高 |
| PCB 工作量 | 键盘加接收器两块 PCB | 更换主控或双 SoC |
| 低功耗潜力 | 中 | 高 |
| 调试可控性 | 高 | 中低 |
| 第一版成功概率 | 较高 | 较低 |
| 长期标准化 | 私有协议 | 强 |

## 决策门槛

在改变主 PCB 前进行两个独立实验：

1. ESP32-S3 双板台架：发送模拟或录制的 16 kHz 单声道音频，接收端输出 USB UAC，
   同时往返传输 Codex HID/RPC；记录丢包、端到端延迟和录音电流。
2. nRF5340 Audio DK 台架：直接连接目标 Mac 和 Windows 电脑，确认能否被识别为可用
   的输入麦克风，并验证与 BLE HID 同时工作。

若实验 1 达标，进入 2.4 GHz 接收器 v1.5。实验 2 只有在目标电脑原生兼容、无接收器
价值明确且移植成本可接受时，才允许替换主控架构。

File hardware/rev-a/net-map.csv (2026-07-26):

function | signal | gpio_or_net | notes
Matrix row 0 | ROW0 | GPIO4 | Active low scan
Matrix row 1 | ROW1 | GPIO5 | Active low scan
Matrix row 2 | ROW2 | GPIO6 | Active low scan
Matrix row 3 | ROW3 | GPIO7 | Active low scan
Matrix column 0 | COL0 | GPIO8 | Internal pull-up plus optional 10 kOhm footprint
Matrix column 1 | COL1 | GPIO9 | Internal pull-up plus optional 10 kOhm footprint
Matrix column 2 | COL2 | GPIO10 | Internal pull-up plus optional 10 kOhm footprint
Matrix column 3 | COL3 | GPIO11 | Internal pull-up plus optional 10 kOhm footprint
Encoder phase A | ENC_A | GPIO12 | Direct input with RC footprint
Encoder phase B | ENC_B | GPIO13 | Direct input with RC footprint
Joystick X | JOY_X | GPIO1 | ADC1 input with 100 nF footprint
Joystick Y | JOY_Y | GPIO2 | ADC1 input with 100 nF footprint
Communication touch | COMM_TOUCH | GPIO14 | Direct service control independent of matrix
RGB data | RGB_DATA | GPIO15 | Feeds 74AHCT1G125 then LED chain
Charger status 1 | CHG_STAT1 | GPIO16 | Open-drain input
Fuel gauge SDA | I2C_SDA | GPIO17 | 4.7 kOhm pull-up to 3V3
Fuel gauge SCL | I2C_SCL | GPIO18 | 4.7 kOhm pull-up to 3V3
USB D- | USB_DN | GPIO19 | 90 Ohm differential pair
USB D+ | USB_DP | GPIO20 | 90 Ohm differential pair
Charger status 2 | CHG_STAT2 | GPIO21 | Open-drain input
LED rail enable | LED_5V_EN | GPIO42 | Low at reset; enables TPS61023
UART RX | UART_RX | GPIO44 | Service pads only
UART TX | UART_TX | GPIO43 | Service pads only
Fuel alert | FUEL_ALRT | GPIO40 | Open-drain wake source
Optional PDM clock | MIC_CLK | GPIO47 | DNP on Rev A
Optional PDM data | MIC_DATA | GPIO48 | DNP on Rev A
Matrix R0C0 | AGENT_1 | ROW0/COL0 | SW1 plus diode
Matrix R0C1 | AGENT_2 | ROW0/COL1 | SW2 plus diode
Matrix R0C2 | AGENT_3 | ROW0/COL2 | SW3 plus diode
Matrix R0C3 | AGENT_4 | ROW0/COL3 | SW4 plus diode
Matrix R1C0 | AGENT_5 | ROW1/COL0 | SW5 plus diode
Matrix R1C1 | AGENT_6 | ROW1/COL1 | SW6 plus diode
Matrix R1C2 | FAST | ROW1/COL2 | SW7 plus diode
Matrix R1C3 | APPROVE | ROW1/COL3 | SW8 plus diode
Matrix R2C0 | DECLINE | ROW2/COL0 | SW9 plus diode
Matrix R2C1 | FORK | ROW2/COL1 | SW10 plus diode
Matrix R2C2 | MIC_KEY | ROW2/COL2 | SW11 plus diode
Matrix R2C3 | SEND | ROW2/COL3 | SW12 plus diode
Matrix R3C0 | ENC_PUSH | ROW3/COL0 | ENC1 switch plus diode
Matrix R3C1 | JOY_PUSH | ROW3/COL1 | JOY1 center switch plus diode
Matrix R3C2 | SPARE_1 | ROW3/COL2 | DNP pads and diode footprint
Matrix R3C3 | SPARE_2 | ROW3/COL3 | DNP pads and diode footprint

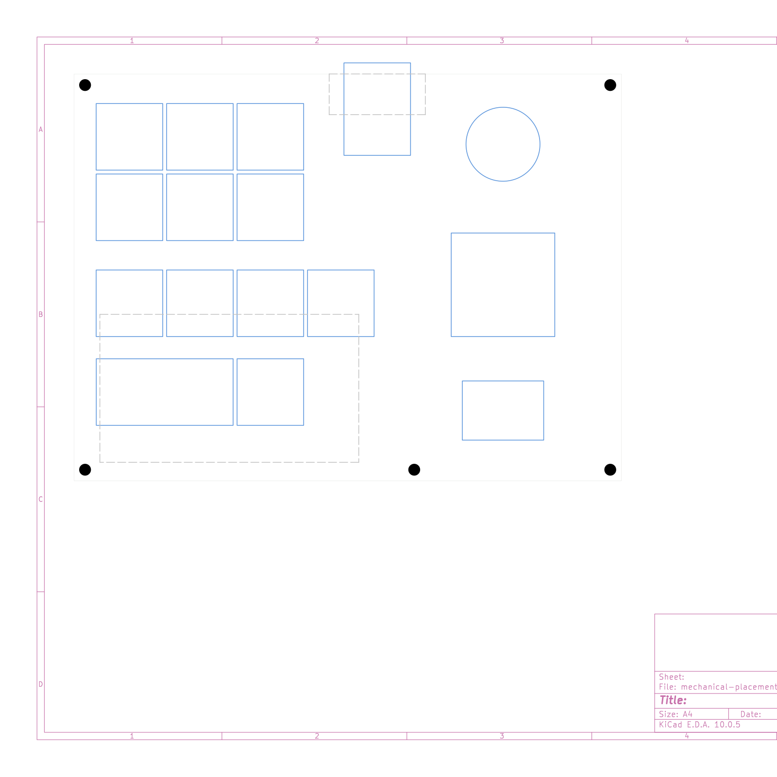
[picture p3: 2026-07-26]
hardware/rev-a/mechanical-placement-preview.png

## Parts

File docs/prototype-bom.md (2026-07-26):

# Phase 0/1 prototype BOM

Buy only the protocol-bench parts first. The integrated battery PCB should wait
until USB recognition is proven on the actual ChatGPT Desktop build.

## Phase 0: one-control protocol bench

| Item | Quantity | Notes |
| --- | ---: | --- |
| ESP32-S3-DevKitC-1-N8R8 | 1 | Purchased variant; use native USB for HID, PSRAM is optional for this milestone |
| Data-capable USB cable | 1 | USB-C or Micro-B according to the board revision |
| Momentary button | 2 | Current bench firmware maps GPIO4/GPIO5 to Agent 1/Agent 2 |
| Breadboard/jumpers | 1 set | For later encoder and joystick checks |

## Phase 1: full input and lighting breadboard

| Item | Quantity | Notes |
| --- | ---: | --- |
| MX-compatible switches | 12 | Choose feel first; hot-swap sockets come with the PCB |
| EC11 push encoder | 1 | Detent count and shaft length depend on the enclosure |
| Two-axis joystick breakout | 1 | Spring-centered, two analog outputs; validate mechanics before PCB |
| Addressable RGB breakout/strip | 20 pixels | Six Agent, six Command, eight perimeter pixels |
| 1N4148 DO-35 diodes | 16 | Through-hole parts for the breadboard; final PCB uses SMD 1N4148W |
| 10 kohm resistors | assorted | Pull-ups and bench configuration |
| 100 nF and 10 uF capacitors | assorted | Local decoupling for breadboard checks |

## PCB-alpha power parts

These are architecture selections, not a purchase order. Confirm package and
assembly availability with the PCB supplier before schematic capture.

| Function | Preferred part/class | Reason |
| --- | --- | --- |
| Charger and load sharing | BQ24074 | Single-cell charger with power path |
| Fuel gauge | MAX17048 | Low-power 1-cell state-of-charge reporting |
| 3.3 V rail | 500 mA+ buck-boost regulator | Stable MCU rail across the LiPo range |
| 5 V RGB rail | Enable-controlled boost regulator | Stable LED behavior and true shutdown |
| RGB level shift | 74AHCT1G125-class buffer | Clean 3.3 V to 5 V data edge |
| USB protection | Low-capacitance USB 2.0 ESD array | Protect D+ and D- without excessive loading |
| Battery | Protected 1S LiPo, 1,500-2,000 mAh | Final dimensions follow the enclosure |

Use a 500 mA USB input-current limit for the first PCB. LED firmware must cap
brightness and estimated current so the system remains stable while charging.

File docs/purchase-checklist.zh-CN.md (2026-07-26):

# Codex Console DIY 采购清单

更新日期：2026-07-26

采购和最终键盘设计并行进行。通用功能件与低风险设计样品可以同步购买；PCB 投产、
电池定型和最终外壳加工等不可逆动作仍受验证门槛约束。

## 第一批：协议验证台（已购买）

- [x] ESP32-S3-DevKitC-1-N8R8
- [x] 数据 USB 线
- [x] 830 孔面包板
- [x] 20 cm 杜邦线
- [x] 数字万用表
- [x] 6 x 6 mm 常开轻触按键

第一批到货后验证 BLE、原生 USB HID 和单按键事件。同时开始 1:1 布局、结构草模
和原理图 Rev A，不等待协议验证全部结束。

第一阶段现已通过：原生 USB、BLE、USB 优先与 BLE 自动回退、GPIO4/GPIO5 双按键
及 ChatGPT Agent 1/Agent 2 行为均已完成实机验证。第二批按键矩阵材料可以购买。

## 第二批：完整输入、灯光面包板和设计样品

这一批一边使用易插面包板的模块验证电气和固件，一边用实物样品确定最终外形、
手感和机械尺寸。

| 物料 | 建议规格或搜索词 | 数量 | 用途 |
| --- | --- | ---: | --- |
| 轻触按键 | 6 x 6 x 5 mm，面包板直插，常开 | 20 个 | 组成 4 x 4 按键矩阵，包含备件 |
| 开关二极管 | 1N4148，DO-35 直插玻璃管 | 50 个 | 每个矩阵位置一个，防止串键 |
| 旋转编码器模块 | KY-040，EC11，带按压，已焊排针 | 2 个 | 验证顺逆时针、单击和长按 |
| 双轴摇杆模块 | KY-023 或 HW-504，PS2 摇杆模块 | 1 个 | 验证 X/Y 模拟量和方向死区 |
| 可寻址灯带 | WS2812B，5 V，30 灯/米，IP30 裸板 | 1 米 | 使用其中 20 颗验证按键和边缘灯效 |
| 逻辑电平转换器 | SN74AHCT125N，DIP-14 直插 | 2 片 | 将 ESP32 的 3.3 V 数据转换为 5 V |
| 电阻包 | 1/4 W，包含 330/470 欧和 10 千欧 | 1 包 | LED 数据保护、上拉和实验配置 |
| 陶瓷电容 | 100 nF，直插 | 20 个 | 模块去耦 |
| 电解电容 | 10 uF，10 V 或更高 | 10 个 | 电源局部缓冲 |
| 大电解电容 | 1000 uF，10 V 或更高 | 2 个 | WS2812B 电源入口缓冲 |
| LED 独立电源 | 稳压 5 V、2 A 电源及匹配的低压转接端子 | 1 套 | 不让 20 颗 LED 的电流经过开发板 |
| 第二块面包板 | 830 孔，与第一块可并排拼接 | 1 块 | 可选，但完整矩阵布线时很有用 |

购买注意：

- 1N4148 要买直插 DO-35，不买给 PCB 贴片用的 1N4148W。
- 电平转换器要买 `AHCT` 或 `HCT`，不买常见的 BSS138 双向 I2C 转换板。
- WS2812B 买非防水 IP30，容易剪裁和焊接；不要买 144 灯/米版本。
- 第二阶段的摇杆和旋钮是功能验证模块，不会直接装进最终外壳。
- LED 独立供电时必须与 ESP32 共地，固件限制全局亮度。

### 同步购买的设计样品

| 物料 | 建议规格 | 数量 | 用途 |
| --- | --- | ---: | --- |
| MX 透明轴试轴包 | 线性、段落、有声各 3 个 | 9 个 | 比较手感和噪声 |
| MX 透光空白键帽 | 1U 十二个、2U 一个 | 1 组 | 做 1:1 布局和灯光扩散测试 |
| 2U 卫星轴 | 板装和 PCB 装各一套 | 2 套 | 确定 Mic 键结构 |
| MX 热插拔轴座 | 凯华兼容 | 20 个 | 冻结 PCB 封装 |
| 裸 EC11 编码器 | 15 mm、20 mm 轴高各一个 | 2 个 | 选择旋钮高度 |
| 编码器旋钮 | 约 15/18/20 mm 直径 | 3 个 | 比较操作空间和比例 |
| 摇杆样品 | PS2 全尺寸、PSP 紧凑型各一个 | 2 个 | 比较行程、精度和安装高度 |
| 半透明材料小样 | 乳白亚克力或半透明 PETG，1-3 mm | 1 组 | 选择灯光扩散结构 |
| 数显卡尺 | 0-150 mm | 1 把 | 测量元件和外壳尺寸 |

## 第三批：电池、机械结构和 PCB Alpha

这一批的原理图、PCB 和外壳设计与功能验证同步推进，但不立即进行最终投产。需要在
BLE、USB、按键矩阵、旋钮、摇杆和 20 颗 LED 联合验证后冻结生产文件。

### 电池电源验证模块

| 物料 | 建议规格 | 数量 | 下单条件 |
| --- | --- | ---: | --- |
| 充电和电源路径模块 | BQ24074 开发板，带 Load Sharing/Power Path | 1 | 第二阶段通过 |
| 电量计模块 | MAX17048 开发板，I2C，适配单节锂电 | 1 | 第二阶段通过 |
| 3.3 V 稳压模块 | 升降压，连续输出至少 500 mA | 1 | 确认开发板供电接法后 |
| 5 V LED 升压模块 | 带 EN 使能，连续输出至少 2 A | 1 | 测得实际 LED 峰值电流后 |
| 锂聚合物电池 | 1S、3.7 V、带保护板、1500-2000 mAh、JST-PH 2.0 | 1 | 外壳内部尺寸冻结后 |
| 电源开关 | 额定电流至少 2 A | 2 | PCB 和外壳开孔冻结后 |
| JST-PH 2.0 线材 | 带插头硅胶线 | 3 条 | 必须先核对正负极性 |

不要购买 TP4056 充电板来同时承担“边充边用”。不要手工购买或焊接裸的
BQ24074/MAX17048 小封装芯片，模块验证通过后交给 PCB 贴片装配。

### 最终控制和结构件

| 物料 | 暂定规格 | 计划数量 | 下单条件 |
| --- | --- | ---: | --- |
| MX 机械轴 | 3 脚或 5 脚、透明上盖、兼容 RGB；PCB 封装兼容两者 | 补齐到 15 个 | 试轴结果确认后 |
| MX 热插拔轴座 | 第二批样品选定的凯华兼容型号 | 补齐到 20 个 | PCB 封装确认后 |
| 透光键帽 | MX 十字轴；11 个 1U、1 个 2U | 使用第二批样品 | 最终布局冻结后 |
| 2U 卫星轴 | 第二批样品中选定的安装方式 | 1 套 | 确认保留 2U Mic 键后 |
| 裸 EC11 编码器和旋钮 | 轴高、轴形和螺纹按外壳选择 | 各 2/1 个 | 外壳高度冻结后 |
| 最终摇杆 | 弹簧回中、双模拟输出、可固定安装 | 2 个 | 完成手感和高度样机后 |
| PCB Alpha | 优先 4 层，含 SMT 贴片，先做 5 片 | 1 批 | 全部原理图和封装审查通过后 |
| 外壳样件 | 3D 打印上壳、底壳和定位板 | 2 套 | PCB 外形冻结后 |
| 紧固件 | M2/M2.5 螺丝、铜柱、热熔螺母 | 1 包 | 外壳孔位冻结后 |

### 装配工具

| 工具 | 建议规格 | 数量 |
| --- | --- | ---: |
| 恒温电烙铁 | 60 W 或以上，可换细焊头 | 1 |
| 焊锡丝 | 0.6-0.8 mm，正规品牌 | 1 卷 |
| 助焊剂和吸锡带 | 电子焊接用 | 各 1 |
| 精密镊子、斜口钳 | 小型电子装配用 | 各 1 |
| 硅胶焊接垫和护目镜 | 耐热、防飞溅 | 各 1 |

焊接只在通风良好的位置进行。锂电池禁止直接焊接电芯、刺穿、挤压或反接。

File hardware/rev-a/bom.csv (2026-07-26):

group | ref | qty | preferred_part | package_or_size | populate_rev_a | selection_note
MCU | U1 | 1 | ESP32-S3-WROOM-1-N8R8 | Module | Yes | Matches validated N8R8 platform
USB | J1 | 1 | HRO TYPE-C-31-M-12 | USB-C 16-pin | Yes | USB 2.0 device only
USB | U7 | 1 | TPD2EUSB30DRTR | SOT-9X3 DRT 3-pin | Yes | Low-capacitance D+/D- ESD protection
USB | R_CC1 R_CC2 | 2 | 5.1 kOhm 1% | 0402 | Yes | USB-C device Rd
USB | R_USB1 R_USB2 | 2 | 22 Ohm 1% | 0402 | Yes | Place near ESP32 module
Power | U2 | 1 | BQ24074RGTR | VQFN-16 3x3 | Yes | 1-cell charger with PowerPath
Power | U3 | 1 | TPS63070RNMR | VQFN-HR-15 3x2.5 | Yes | 3.3 V buck-boost with current headroom
Power | U4 | 1 | TPS61023DRLR | SOT-563-6 | Yes | Enable-controlled 5 V RGB boost
Power | U5 | 1 | MAX17048G+T10 | TDFN-8 2x2 | Yes | Single-cell fuel gauge
Power | J2 | 1 | JST-PH 2.0 right-angle | 2-pin | Yes | Verify pack polarity before insertion
Power | SW_PWR | 1 | JS102011SAQN | SPDT slide | Yes | Controls regulator enables not raw battery current
Power | BAT1 | 1 | Protected LiPo 604070 | 70x40x7 max | External | 1500-2000 mAh with JST-PH 2.0
RGB | U6 | 1 | SN74AHCT1G125DBVR | SOT-23-5 | Yes | 3.3 V to 5 V data buffer
RGB | LED1-LED20 | 20 | SK6812MINI-E | 3.5x3.5 reverse mount | Yes | 12 key plus 8 perimeter pixels
RGB | R_RGB | 1 | 330 Ohm | 0402 | Yes | Series resistor at buffer output
Keys | HS1-HS12 | 12 | Kailh MX hot-swap socket | MX socket | Yes | Use verified KiCad footprint
Keys | SW1-SW12 | 12 | Gateron G Pro 3.0 Brown | MX 5-pin | External | Transparent top tactile default; PCB footprint supports 3/5-pin MX
Keys | D1-D14 | 14 | 1N4148W | SOD-123 | Yes | One per populated matrix control
Keys | D15-D16 | 2 | 1N4148W | SOD-123 | No | Spare matrix positions
Encoder | ENC1 | 1 | EC11E15244G1 | THT 11 mm | Yes | 30 detents 15 pulses push switch 20 mm D shaft
Encoder | KNOB1 | 1 | 20 mm aluminum knob | D-shaft | External | Final color after case sample
Joystick | JOY1 | 1 | RKJXV122400R | THT 18.2x21.7 | Yes | Current standard Alps part with center push
Touch | TOUCH1 | 1 | PCB copper electrode | 22x16 | Yes | 510 Ohm series and ESD footprint
Audio | MIC1 | 1 | MP34DT06JTR | HCLGA-4 | No | PDM microphone option only; USB Audio not enabled
Mechanical | PLATE1 | 1 | Black FR4 switch plate | 1.5 mm | External | MX plate and control openings
Mechanical | STAB1 | 1 | 2U screw-in stabilizer | PCB mount | External | Mic key only
Keycaps | KC_AGENT | 6 | Frosted translucent XDA blank | 1U | External | Agent status light
Keycaps | KC_CMD | 5 | Charcoal XDA PBT blank | 1U | External | UV printed or laser marked
Keycaps | KC_MIC | 1 | Charcoal XDA PBT blank | 2U | External | Mic legend
Mechanical | CASE1 | 1 | 3D printed ASA or PETG | 154x116x18 | External | Two-piece enclosure plus touch insert
Mechanical | FASTENERS | 1 | M3 heat-set inserts and screws | M3 | External | Five PCB supports

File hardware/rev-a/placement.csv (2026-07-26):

ref | type | x_mm | y_mm | rotation_deg | top_envelope_mm | notes
SW1 | MX_AGENT_1 | 18.00 | 20.00 | 0 | 18x18 | 1U frosted keycap
SW2 | MX_AGENT_2 | 37.05 | 20.00 | 0 | 18x18 | 1U frosted keycap
SW3 | MX_AGENT_3 | 56.10 | 20.00 | 0 | 18x18 | 1U frosted keycap
SW4 | MX_AGENT_4 | 18.00 | 39.05 | 0 | 18x18 | 1U frosted keycap
SW5 | MX_AGENT_5 | 37.05 | 39.05 | 0 | 18x18 | 1U frosted keycap
SW6 | MX_AGENT_6 | 56.10 | 39.05 | 0 | 18x18 | 1U frosted keycap
SW7 | MX_FAST | 18.00 | 65.00 | 0 | 18x18 | 1U charcoal keycap
SW8 | MX_APPROVE | 37.05 | 65.00 | 0 | 18x18 | 1U charcoal keycap
SW9 | MX_DECLINE | 56.10 | 65.00 | 0 | 18x18 | 1U charcoal keycap
SW10 | MX_FORK | 75.15 | 65.00 | 0 | 18x18 | 1U charcoal keycap
SW11 | MX_MIC_2U | 27.53 | 89.00 | 0 | 37x18 | 2U charcoal keycap and PCB stabilizer
SW12 | MX_SEND | 56.10 | 89.00 | 0 | 18x18 | 1U charcoal keycap
ENC1 | EC11E15244G1 | 119.00 | 22.00 | 0 | D20 knob | 7.2 mm panel shaft hole
JOY1 | RKJXV122400R | 119.00 | 60.00 | 0 | 28x28 cap travel | 22 mm panel opening
TOUCH1 | COMM_PAIR_PAD | 119.00 | 94.00 | 0 | 22x16 | 1.0 mm plastic touch window
J1 | USB_C | 38.00 | 3.00 | 180 | 16x9 | rear edge centered at x 38
SW_PWR | POWER_SLIDE | 136.00 | 3.00 | 180 | 14x6 | rear edge
U1 | ESP32_S3_WROOM_1_N8R8 | 85.00 | 12.50 | 0 | 18x25 | module antenna faces rear edge
BAT1 | LIPO_604070 | 45.00 | 88.00 | 0 | 70x40x7 | lower battery layer centered here
H1 | M3_MOUNT | 6.00 | 6.00 | 0 | D3.2 | case and plate mount
H2 | M3_MOUNT | 148.00 | 6.00 | 0 | D3.2 | case and plate mount
H3 | M3_MOUNT | 6.00 | 110.00 | 0 | D3.2 | case and plate mount
H4 | M3_MOUNT | 148.00 | 110.00 | 0 | D3.2 | case and plate mount
H5 | M3_MOUNT | 95.00 | 110.00 | 0 | D3.2 | center support

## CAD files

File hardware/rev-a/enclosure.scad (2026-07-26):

// Codex Console Alpha Rev A mechanical reference.
// Units are millimeters. Print prototypes only after checking the real parts.
$fn = 64;

outer_w = 154;
outer_d = 116;
body_h = 18;
wall = 2.0;
corner_r = 6;
plate_t = 1.5;
pcb_z = 11;

key_centers = [
    [18, 20], [37.05, 20], [56.10, 20],
    [18, 39.05], [37.05, 39.05], [56.10, 39.05],
    [18, 65], [37.05, 65], [56.10, 65], [75.15, 65],
    [27.525, 89], [56.10, 89]
];

mounts = [[6, 6], [148, 6], [6, 110], [148, 110], [95, 110]];

module rounded_rect_2d(w, d, r) {
    offset(r = r) square([w - 2*r, d - 2*r], center = true);
}

module rounded_box(w, d, h, r) {
    linear_extrude(height = h) rounded_rect_2d(w, d, r);
}

module at_xy(p, z = 0) {
    translate([p[0] - outer_w/2, p[1] - outer_d/2, z]) children();
}

module bottom_shell() {
    difference() {
        rounded_box(outer_w, outer_d, body_h, corner_r);
        translate([0, 0, 2]) rounded_box(outer_w - 2*wall, outer_d - 2*wall,
                                         body_h, corner_r - wall);
        // Rear connector openings: USB-C and power slide switch.
        translate([38 - outer_w/2, -outer_d/2, 9]) cube([17, 8, 8], center = true);
        translate([136 - outer_w/2, -outer_d/2, 9]) cube([15, 8, 6], center = true);
    }

    for (p = mounts) {
        at_xy(p, 2) difference() {
            cylinder(h = pcb_z - 2, d = 7);
            cylinder(h = pcb_z, d = 2.7);
        }
    }
}

module switch_plate() {
    difference() {
        linear_extrude(height = plate_t)
            rounded_rect_2d(150, 112, 4);

        for (p = key_centers) {
            at_xy(p, plate_t/2) cube([14.0, 14.0, plate_t + 0.2], center = true);
        }

        // EC11 shaft, joystick travel, and communication touch insert.
        at_xy([119, 22], -0.1) cylinder(h = plate_t + 0.2, d = 7.2);
        at_xy([119, 60], -0.1) cylinder(h = plate_t + 0.2, d = 22);
        at_xy([119, 94], plate_t/2) cube([22, 16, plate_t + 0.2], center = true);

        // Approximate 2U stabilizer access. Replace with the selected stabilizer drawing.
        at_xy([27.525 - 11.9, 89], plate_t/2)
            cube([6.8, 12, plate_t + 0.2], center = true);
        at_xy([27.525 + 11.9, 89], plate_t/2)
            cube([6.8, 12, plate_t + 0.2], center = true);

        for (p = mounts) {
            at_xy(p, -0.1) cylinder(h = plate_t + 0.2, d = 3.2);
        }
    }
}

module battery_dummy() {
    color([0.3, 0.55, 0.8, 0.45])
        at_xy([45, 88], 5.7) cube([70, 40, 7], center = true);
}

module pcb_dummy() {
    color([0.1, 0.45, 0.25, 0.45])
        translate([0, 0, pcb_z]) rounded_box(148, 110, 1.6, 2);
}

// Assembly view. Comment individual modules to export separate parts.
color([0.20, 0.22, 0.24]) bottom_shell();
battery_dummy();
pcb_dummy();
color([0.08, 0.09, 0.10]) translate([0, 0, pcb_z + 6.6]) switch_plate();

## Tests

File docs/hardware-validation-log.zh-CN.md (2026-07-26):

# 实机验证记录

## 2026-07-26：ESP32-S3-DevKitC-1-N8R8 首次上板

测试环境：macOS、ESP32-S3-DevKitC-1-N8R8、原生 USB 数据连接。该开发板的
UART 和原生 USB 接口均为 Micro-USB（Micro-B），不是 USB-C。

| 项目 | 结果 | 记录 |
| --- | --- | --- |
| 系统识别开发板 | 通过 | 初始设备为 Espressif USB Serial/JTAG |
| 芯片识别 | 通过 | ESP32-S3 revision v0.2 |
| Flash | 通过 | 8 MB |
| PSRAM | 通过 | 工具报告 Embedded PSRAM 8 MB (AP_3v3) |
| 协议单元测试 | 通过 | 6/6 |
| N8R8 固件编译 | 通过 | `qio_opi`、`BOARD_HAS_PSRAM` |
| 固件烧录与校验 | 通过 | 全部区段 Hash 校验成功 |
| USB 产品名 | 通过 | Codex Micro |
| USB 厂商名 | 通过 | Work Louder |
| USB VID/PID | 通过 | `0x303A` / `0x8360` |
| ChatGPT Desktop 识别 | 通过 | 用户确认应用中出现 Codex Micro |
| BOOT 按键触发 Agent 1 | 通过 | 快速双击后 ChatGPT 切换到对应任务并回到前台；使用 GPIO0，仅用于开发板台架 |
| 外接 GPIO4 按键 | 通过 | 常开按键接在 GPIO4 与 GND 之间；双击后 ChatGPT 正确回到前台 |
| 外接 GPIO5 按键 | 通过 | Agent 2 单击切换会话，双击将 ChatGPT 带到前台 |
| BLE 配对与识别 | 通过 | macOS 显示 BLE 连接、VID/PID 正确、模拟电量 100% |
| BLE 外接按键 | 通过 | 仅通过 UART 口供电，原生 USB HID 断开；双击后 ChatGPT 正确回到前台 |
| USB/BLE 切换 | 通过 | 两接口同时连接时按键日志显示 USB；拔掉原生 USB 后自动显示 BLE |

首次通过手动 `BOOT + RST/EN` 进入下载模式，然后使用原生 USB Serial/JTAG 端口
烧录。烧录完成后单独按 `RST/EN` 启动应用，设备重新枚举为 Codex Micro。

Agent 1 的单击行为不会主动将 ChatGPT 带到前台，首次测试因此看起来没有响应。
改用 350 ms 内快速双击后，ChatGPT 正确切换到对应任务并回到前台，确认 USB HID
按键事件链路已打通。

外接按键首次接线时误将杜邦线套到与 GPIO4 相邻的 RST，引起按键时 USB HID
连接失效。ChatGPT 日志表现为 `could not read from HID device` 和
`transport-unavailable`。断电后将线移至 GPIO4，再次双击验证通过。后续接线检查必须
同时核对丝印和针脚位置，不能只按相邻顺序计数。

BLE 验证时将数据线从原生 USB 口移至 UART 口，仅由 UART 口为开发板供电。
macOS 确认原生 USB Codex Micro 不存在，同时 BLE Codex Micro 已连接，地址为开发板
蓝牙地址，VID/PID 为 `0x303A` / `0x8360`。外接 GPIO4 按键双击后 ChatGPT 正确
回到前台，确认事件未借道原生 USB。

传输切换验证时同时连接 UART 和原生 USB。UART 串口日志对同一外接按键明确显示
`Agent 1 down/up over USB`，证明 BLE 在线时原生 USB 具有优先级。随后保留 UART
供电并拔掉原生 USB，日志显示 `Agent 1 down/up over BLE`，证明无需重启即可自动
回退到 BLE。开发板接口类型只影响当前验证线材，不改变最终 PCB 使用 USB-C 的规划。

双按键验证将 GPIO4/GPIO5 分别映射为 Agent 1/Agent 2，并为每颗按键独立保存采样、
消抖和传输状态。UART 日志确认两颗按键各自生成完整的 down/up 事件；同时按住和
松开时两组事件均被接收，没有串键。ChatGPT 界面进一步确认 GPIO5 按键单击切换
Agent 2 会话，双击切换会话并将 ChatGPT 带到前台。

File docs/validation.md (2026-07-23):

# Validation plan

## Phase 0: protocol bench

- Build and run native framing tests.
- Enumerate VID `0x303A`, PID `0x8360`, usage page `0xFF00`, report ID `6`.
- Verify ChatGPT Desktop exposes Settings > Codex Micro over BLE.
- Repeat over native USB. Treat failure here as a protocol investigation, not a
  PCB problem.
- Press and release Agent 1 at least 100 times on each transport; confirm no
  stuck state.
- Plug and unplug USB while BLE is connected; confirm exactly one action per
  physical edge.

## Phase 1: full input and lighting breadboard

- Scan all matrix positions with diode direction and ghosting tests.
- Verify 10-15 ms debounce without delaying encoder steps.
- Verify encoder CW, CCW, tap, and 500 ms host-interpreted hold.
- Calibrate joystick center at boot and apply deadzone plus directional
  hysteresis.
- Replay all observed Agent colors and breathing states on the six Agent LEDs.
- Apply a hard LED-current and brightness ceiling.

## Phase 2: battery carrier and PCB alpha

- Test USB load sharing at empty, half, and full battery states.
- Measure peak 3.3 V droop during BLE transmit plus an RGB update.
- Verify charge status, battery percentage, low-battery dimming, and shutdown.
- Measure active, idle-lit, idle-dark, BLE advertising, and deep-sleep current.
- Perform at least 20 BLE reconnects and 20 USB enumerate/unplug cycles.
- Forget and re-pair after every HID descriptor or PnP identity change.

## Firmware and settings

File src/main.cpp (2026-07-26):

#include <Arduino.h>

#include "freertos/FreeRTOS.h"
#include "freertos/queue.h"
#include "protocol/ProtocolEngine.h"
#include "transports/BleTransport.h"
#include "transports/TransportRouter.h"
#include "transports/UsbTransport.h"

namespace {

constexpr uint32_t kDebounceMs = 12;

struct BenchButton {
  uint8_t pin;
  const char* keyId;
  const char* label;
  bool stable = false;
  bool sampled = false;
  uint32_t changedAtMs = 0;
  codex::TransportKind transport = codex::TransportKind::kBle;
};

BenchButton benchButtons[] = {
    {4, "AG00", "Agent 1"},
    {5, "AG01", "Agent 2"},
};

QueueHandle_t incomingQueue = nullptr;
codex::BleTransport ble;
codex::UsbTransport usb;
codex::TransportRouter router(ble, usb);
codex::ProtocolEngine protocol;

void updateBenchButton(BenchButton& button) {
  const bool pressed = digitalRead(button.pin) == LOW;
  if (pressed != button.sampled) {
    button.sampled = pressed;
    button.changedAtMs = millis();
  }
  if (button.sampled == button.stable ||
      millis() - button.changedAtMs < kDebounceMs) {
    return;
  }

  button.stable = button.sampled;
  if (button.stable) {
    button.transport = router.active();
  }
  protocol.sendKey(button.transport, button.keyId, button.stable ? 1 : 0, 0,
                   router);
  Serial.printf("%s %s over %s\n", button.label,
                button.stable ? "down" : "up",
                button.transport == codex::TransportKind::kUsb ? "USB" : "BLE");
}

void updateBenchButtons() {
  for (BenchButton& button : benchButtons) {
    updateBenchButton(button);
  }
}

}  // namespace

void setup() {
  Serial.begin(115200);
  for (const BenchButton& button : benchButtons) {
    pinMode(button.pin, INPUT_PULLUP);
  }

  incomingQueue = xQueueCreate(12, sizeof(codex::IncomingReport));
  if (incomingQueue == nullptr) {
    while (true) {
      delay(1000);
    }
  }

  usb.begin(incomingQueue);
  ble.begin(incomingQueue);
  protocol.setBattery(100, false);
  router.setBattery(100);
  Serial.println("CODEX_CONSOLE_PHASE0_READY");
}

void loop() {
  codex::IncomingReport report;
  while (xQueueReceive(incomingQueue, &report, 0) == pdTRUE) {
    protocol.onReport(report, router);
  }

  updateBenchButtons();
  delay(2);
}

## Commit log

2026-07-23 Bootstrap ESP32-S3 Codex console
2026-07-23 Add staged hardware purchase checklist
2026-07-25 Evaluate wireless microphone transport options
2026-07-26 Record first ESP32-S3 hardware validation
2026-07-26 Validate external Agent button
2026-07-26 Validate USB and BLE transport switching
2026-07-26 Add and validate second Agent button
2026-07-26 Add integrated Alpha hardware design baseline
    [bom.csv, enclosure.scad, mechanical-placement.kicad_pcb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]
2026-07-26 Import Rev A mechanical PCB into JLCEDA
